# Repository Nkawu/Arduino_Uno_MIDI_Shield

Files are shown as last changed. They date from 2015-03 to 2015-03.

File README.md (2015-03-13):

# Arduino Uno MIDI Shield

Follow my [Hackaday Project Page](http://hackaday.io/project/4741-organ-pedalboard-midi-conversion)!

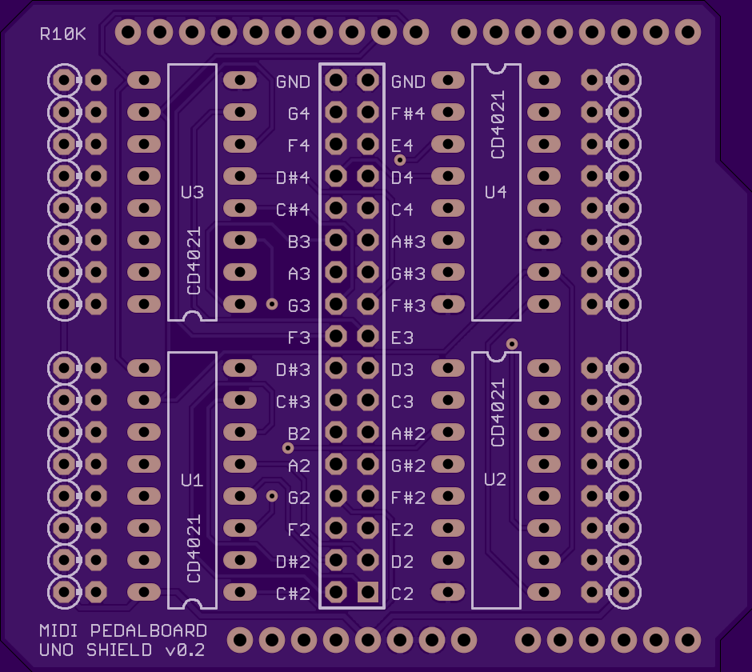
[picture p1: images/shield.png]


This project originated during the conversion of an old AGO spec pipe organ pedalboard to MIDI in order to be used with
[Hauptwerk](https://www.hauptwerk.com) virtual organ software. 

The shield uses 4 daisy chained CD4021 shift registers to read 32 reed switches installed on the pedalboard. The Arduino Uno reads the shift registers and then sends MIDI notes via [Hiduino](https://github.com/ddiakopoulos/hiduino) firmware flashed to the Uno's Atmel ATmega16U2. The Hiduino firmware makes the Arduino Uno appear as a class-compliant USB-MIDI device.

The project contains: 
* Eagle CAD files for an Arduino Uno R3 shield
* Arduino sketch

**NOTE:** This is still a work in progress. I've breadboarded the circuit with a single CD4021 which works perfectly, but I have yet to daisy chain multiple CD4021s on the breadboard. When that has been done I'll have PCBs made at [OSHPark](https://oshpark.com)

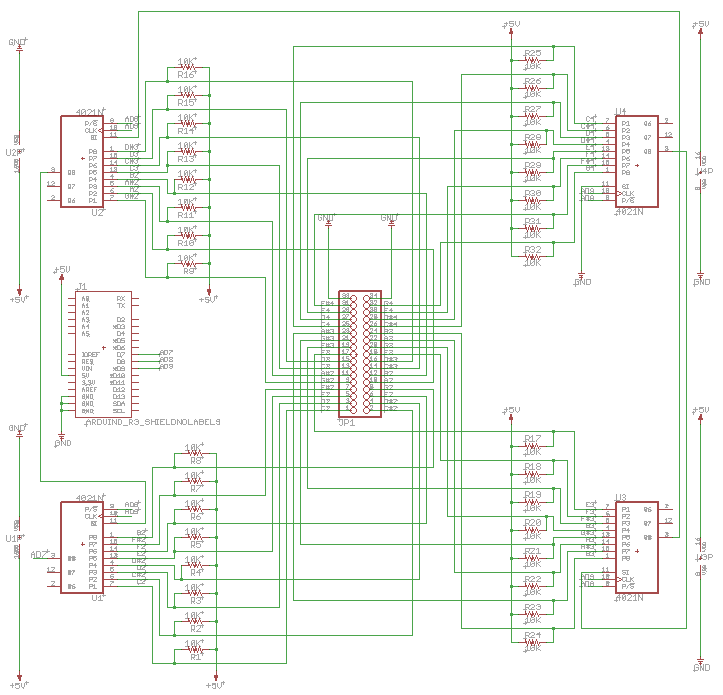
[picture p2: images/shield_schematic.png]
Schematic


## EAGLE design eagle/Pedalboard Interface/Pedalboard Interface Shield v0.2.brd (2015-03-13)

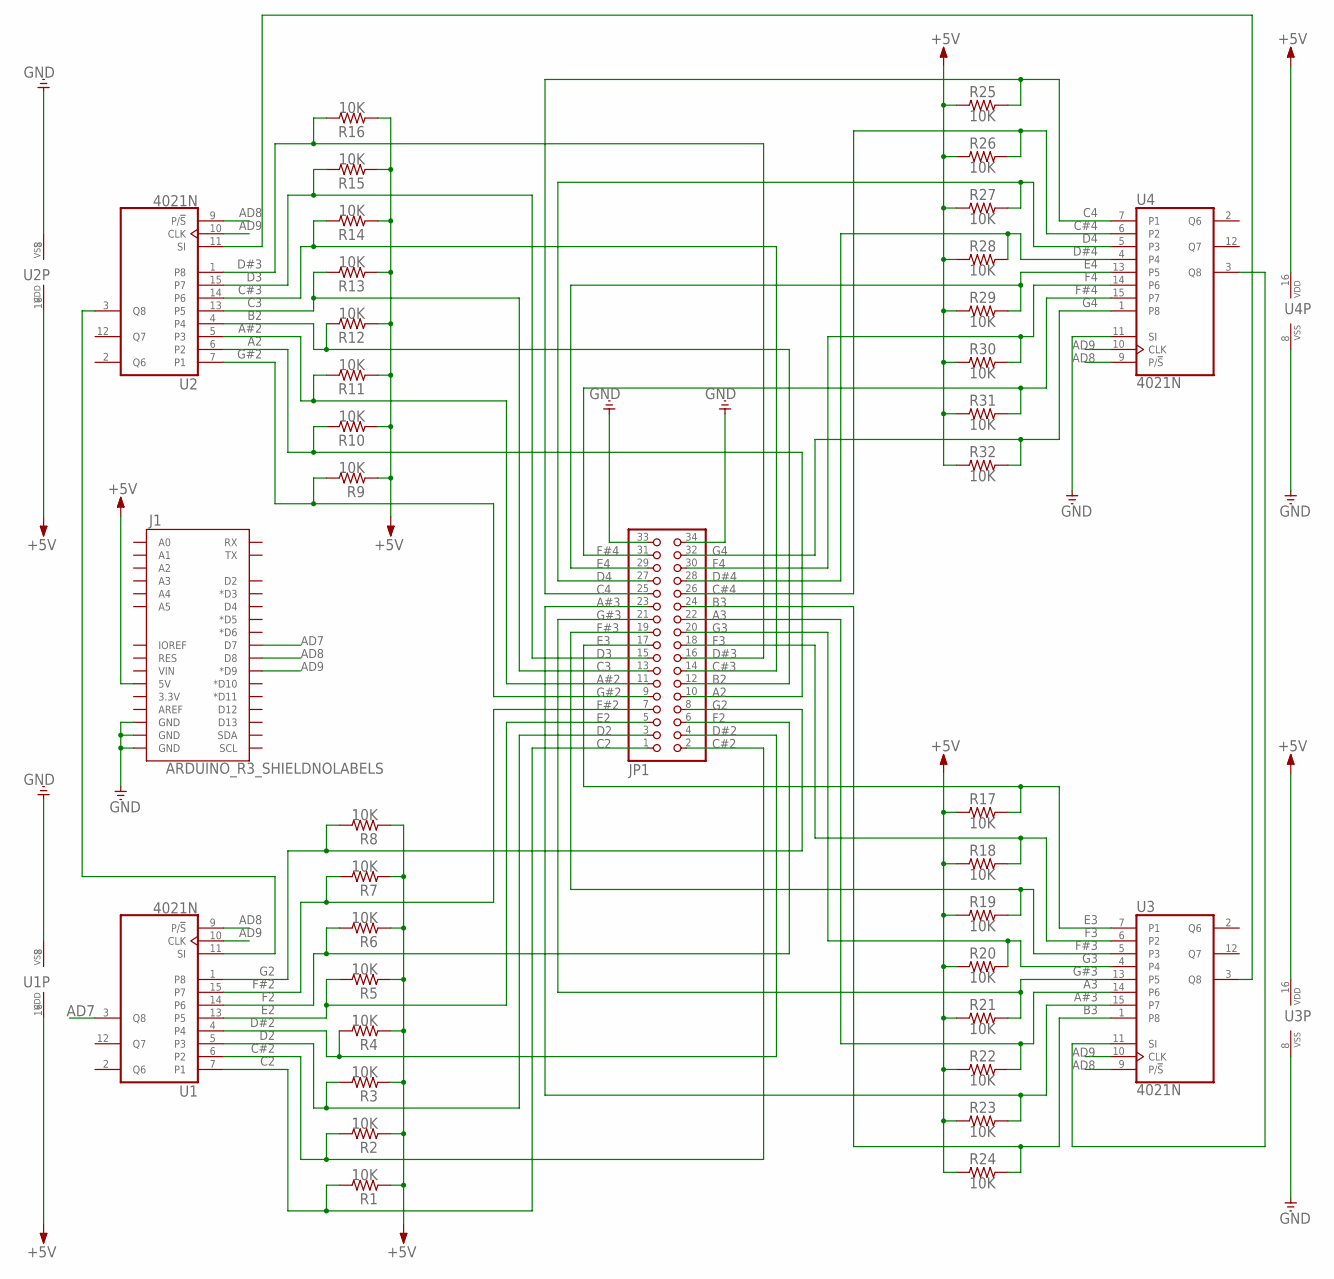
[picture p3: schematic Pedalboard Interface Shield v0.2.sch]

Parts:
J1: ARDUINO_R3_SHIELDNOLABELS; UNO_R3_SHIELD_NOLABELS
JP1: PINHD-2X17; 2X17
R1, R2, R3, R4, R5, R6, R7, R8, R9, R10, R11, R12, R13, R14, R15, R16, R17, R18, R19, R20, R21, R22, R23, R24, R25, R26, R27, R28, R29, R30, R31, R32: 10K; 0207/2V
U1, U2, U3, U4: 4021N; DIL16

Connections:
+5V: J1.5V, R1.1, R2.1, R3.1, R4.1, R5.1, R6.1, R7.1, R8.1, R9.1, R10.1, R11.1, R12.1, R13.1, R14.1, R15.1, R16.1, R17.1, R18.1, R19.1, R20.1, R21.1, R22.1, R23.1, R24.1, R25.1, R26.1, R27.1, R28.1, R29.1, R30.1, R31.1, R32.1, U1.16 (VDD), U2.16 (VDD), U3.16 (VDD), U4.16 (VDD)
A2: JP1.10, R10.2, U2.6 (P2)
A3: JP1.22, R22.2, U3.14 (P6)
A#2: JP1.11, R11.2, U2.5 (P3)
A#3: JP1.23, R23.2, U3.15 (P7)
AD7: J1.D7, U1.3 (Q8)
AD8: J1.D8, U1.9 (P/!S), U2.9 (P/!S), U3.9 (P/!S), U4.9 (P/!S)
AD9: J1.D9 (*D9), U1.10 (CLK), U2.10 (CLK), U3.10 (CLK), U4.10 (CLK)
B2: JP1.12, R12.2, U2.4
B3: JP1.24, R24.2, U3.1 (P8)
C2: JP1.1, R1.2, U1.7 (P1)
C3: JP1.13, R13.2, U2.13 (P5)
C4: JP1.25, R25.2, U4.7 (P1)
C#2: JP1.2, R2.2, U1.6 (P2)
C#3: JP1.14, R14.2, U2.14 (P6)
C#4: JP1.26, R26.2, U4.6 (P2)
D2: JP1.3, R3.2, U1.5 (P3)
D3: JP1.15, R15.2, U2.15 (P7)
D4: JP1.27, R27.2, U4.5 (P3)
D#2: JP1.4, R4.2, U1.4
D#3: JP1.16, R16.2, U2.1 (P8)
D#4: JP1.28, R28.2, U4.4
E2: JP1.5, R5.2, U1.13 (P5)
E3: JP1.17, R17.2, U3.7 (P1)
E4: JP1.29, R29.2, U4.13 (P5)
F2: JP1.6, R6.2, U1.14 (P6)
F3: JP1.18, R18.2, U3.6 (P2)
F4: JP1.30, R30.2, U4.14 (P6)
F#2: JP1.7, R7.2, U1.15 (P7)
F#3: JP1.19, R19.2, U3.5 (P3)
F#4: JP1.31, R31.2, U4.15 (P7)
G2: JP1.8, R8.2, U1.1 (P8)
G3: JP1.20, R20.2, U3.4
G4: JP1.32, R32.2, U4.1 (P8)
G#2: JP1.9, R9.2, U2.7 (P1)
G#3: JP1.21, R21.2, U3.13 (P5)
GND: J1.GND@0 (GND), J1.GND@1 (GND), J1.GND@2 (GND), JP1.33, JP1.34, U1.8 (VSS), U2.8 (VSS), U3.8 (VSS), U4.8 (VSS), U4.11 (SI)
unnamed: U2.11 (SI), U3.3 (Q8)
unnamed: U3.11 (SI), U4.3 (Q8)
unnamed: U1.11 (SI), U2.3 (Q8)

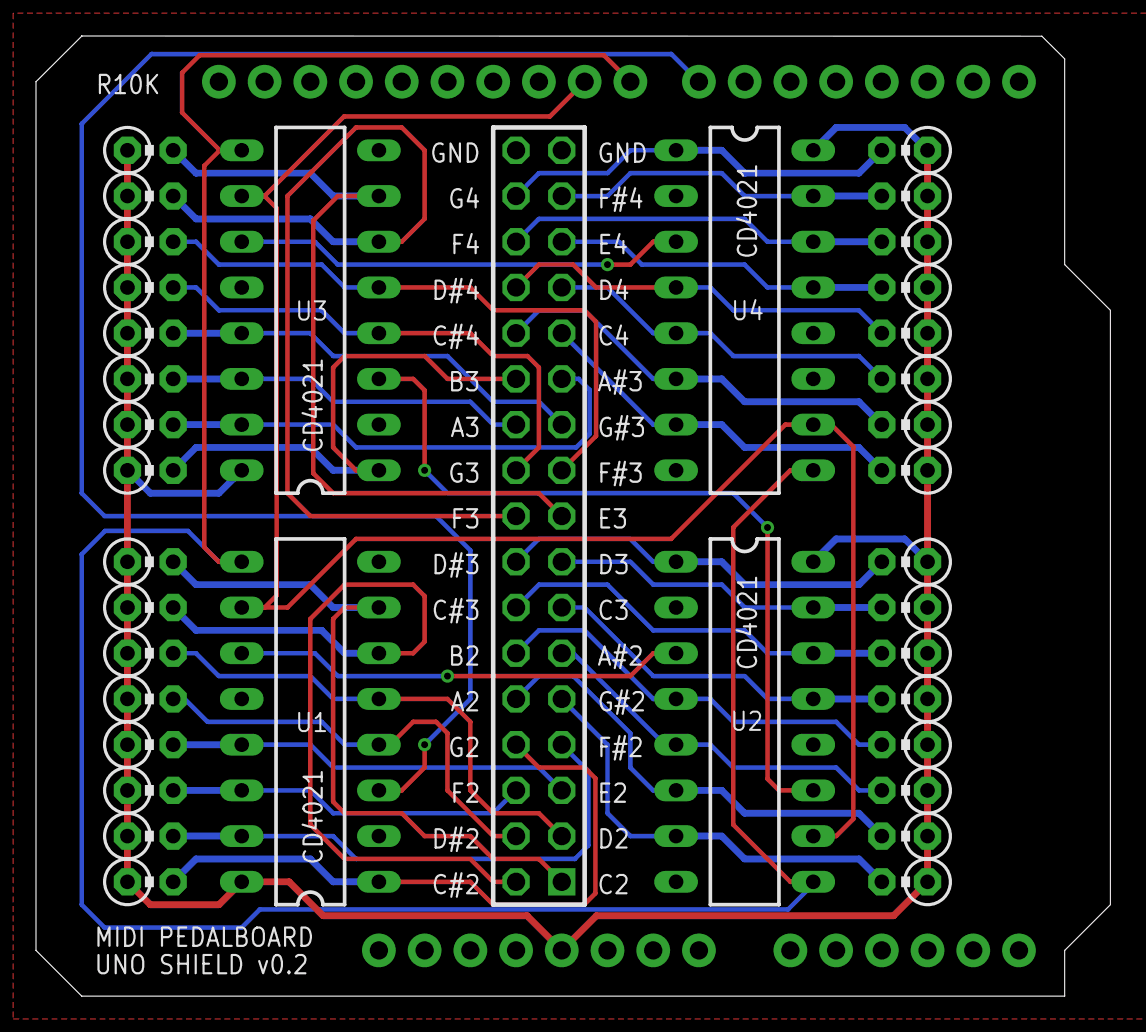
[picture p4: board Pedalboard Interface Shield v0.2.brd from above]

Board: 2 copper layers, 59.7 x 53.3 mm, 38 parts (0 on the bottom side), 40 nets.

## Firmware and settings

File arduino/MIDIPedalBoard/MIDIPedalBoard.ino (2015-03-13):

//**************************************************************
//  Name    : MIDIPedalBoard
//  Author  : Nkawu
//  Date    : 12 March, 2015
//  Version : 1.0
//  Notes   : Read switches connected to CD4021B Shift Register
//          : then send MIDI out via hiduino firmware
//****************************************************************

#include <MIDI.h>

// #define DEBUG

// General settings
#define NUM_INPUTS 32  // 32 switches for AGO Pedalboard C2-G4
#define BTN_DEBOUNCE 75  // Delay to prevent switch bouncing

// MIDI Settings
#define MIDI_CHANNEL 1
#define MIDI_NOTE_OFFSET 36  // MIDI note 36 = C2
#define MIDI_NOTE_ON_VELOCITY 127

// Arduino Pins
#define CLOCKPIN 9  // To CD4012 pin 10 (CLOCK)
#define LATCHPIN 8  // To CD4012 pin 9 (P/S C)
#define DATAPIN 7   // To CD4012 pin 3 (Q8)

#define NUM_REGISTERS (NUM_INPUTS / 8)

byte midiState[NUM_REGISTERS];    // Hold last register state HIGH=OFF
byte switchState[NUM_REGISTERS];  // Hold shift register state HIGH=OFF
unsigned long lastSwitch = 0;     // Holds last switch read time for debouncing switches

#if ! defined(DEBUG)
MIDI_CREATE_DEFAULT_INSTANCE();
#endif

void setup() {
	// Initialize last switch state array
	for (byte i = 0; i < NUM_REGISTERS; i++) {
		midiState[i] = 255;  // 11111111
	}

	#if defined(DEBUG)
	Serial.begin(38400);
	#else	
	// Initialize MIDI
	MIDI.begin(0);
	#endif

	// Define pin modes
	pinMode(CLOCKPIN, OUTPUT); 
	pinMode(LATCHPIN, OUTPUT);
	pinMode(DATAPIN, INPUT);

}


void loop() {

	readShiftRegisters();  // Read current switch positions
	processSwitches();  // Process switches & send MIDI

	#if defined(DEBUG)
	// Add delay to keep up with print statements
	delay(500);
	#endif
}


// Read the shift registers
void readShiftRegisters() {

	#if defined(DEBUG)
	// Serial.println("-------------------");
	// Serial.println("Reading registers");
	#endif

	// Pulse the latch pin: set it to 1 to collect parallel data, then wait
	digitalWrite(LATCHPIN, 1);
	delayMicroseconds(20);

	// Set latch pin to 0 to transmit data serially  
	digitalWrite(LATCHPIN, 0);

	// While the shift register is in serial mode collect each shift register 
	// into a byte. NOTE: the register attached to the chip comes in first.
	for (byte i = 0; i < NUM_REGISTERS; i++) {
		switchState[i] = shiftIn(DATAPIN, CLOCKPIN);
		#if defined(DEBUG)
		// Serial.print("Register #");
		// Serial.print(i);
		// Serial.print(": ");
		// Serial.print(switchState[i]);
		// Serial.print("-");
		// Serial.println(switchState[i], BIN);
		#endif
	}
}


void processSwitches() {

	if (micros() - lastSwitch > BTN_DEBOUNCE) {  // Ignore if we're in the debounce time
		lastSwitch = micros();

		// Process all registers
		for (byte i = 0; i < NUM_REGISTERS; i++) {
			if (switchState[i] != midiState[i]) {  // Don't process if no switches changed
				#if defined(DEBUG)
				// Serial.print("Register #");
				// Serial.print(i);
				// Serial.print(": ");
				// Serial.print(switchState[i]);
				// Serial.print("-");
				// Serial.println(midiState[i]);
				#endif
				for (byte j = 0; j < 8; j++ ) {
					// Read old & new switch states
					byte switchStateValue = bitRead(switchState[i], j);
					byte midiStateValue   = bitRead(midiState[i], j);
					
					#if defined(DEBUG)
					// Serial.print("  Byte #");
					// Serial.print(j);
					// Serial.print(": ");
					// Serial.print(switchStateValue);
					// Serial.print("-");
					// Serial.println(midiStateValue);
					#endif

					// Switch has changed, send MIDI command
					if (switchStateValue != midiStateValue) {
						byte note = (i * 8) + j + MIDI_NOTE_OFFSET;  // MIDI note for current switch
						if (switchStateValue == 1) {  // HIGH = switch open
							#if defined(DEBUG)
							Serial.print("Note OFF ");
							#else
							MIDI.sendNoteOff(note, 0, MIDI_CHANNEL);
							#endif
						} else {  // LOW = switch closed
							#if defined(DEBUG)
							Serial.print("Note ON ");
							#else
							MIDI.sendNoteOn(note, MIDI_NOTE_ON_VELOCITY, MIDI_CHANNEL);
							#endif
						}
						#if defined(DEBUG)
						Serial.print(i);
						Serial.print("-");
						Serial.print(j);
						Serial.print(": ");
						Serial.println(note);
						#endif
					}
				}
				midiState[i] = switchState[i];  // Save current switch state
			}
		}
	}
}


// Returns a byte with each bit in the byte corresponding
// to a pin on the shift register. leftBit 7 = Pin 7 / Bit 0= Pin 0
// From: http://arduino.cc/en/Tutorial/ShftIn21
byte shiftIn(int myDataPin, int myClockPin) { 
	int i;
	int temp = 0;
	int pinState;
	byte myDataIn = 0;

	pinMode(myClockPin, OUTPUT);
	pinMode(myDataPin, INPUT);

	// Hold the clock pin high 8 times (0,..,7) at the end of each time through
	// the for loop. At the beginning of each loop when the clock is set low, 
	// it will be doing the necessary low to high drop to cause the shift
	// register's DataPin to change state based on the value of the next bit in 
	// its serial information flow. The register transmits the information about 
	// the pins from pin 7 to pin 0 so that is why our function counts down.
	for (i=7; i>=0; i--) {
		digitalWrite(myClockPin, 0);  // Set clock low
		delayMicroseconds(2);
		temp = digitalRead(myDataPin);
		if (temp) {
			pinState = 1;
			// Set the bit to 0 no matter what
			myDataIn = myDataIn | (1 << i);
		} else {
			// Turn it off -- only necessary for debuging
			// print statement since myDataIn starts as 0
			pinState = 0;
		}

		digitalWrite(myClockPin, 1);
	}
	return myDataIn;
}

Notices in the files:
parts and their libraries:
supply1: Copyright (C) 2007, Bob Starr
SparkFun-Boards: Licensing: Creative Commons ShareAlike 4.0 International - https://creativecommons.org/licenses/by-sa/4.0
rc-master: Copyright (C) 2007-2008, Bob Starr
